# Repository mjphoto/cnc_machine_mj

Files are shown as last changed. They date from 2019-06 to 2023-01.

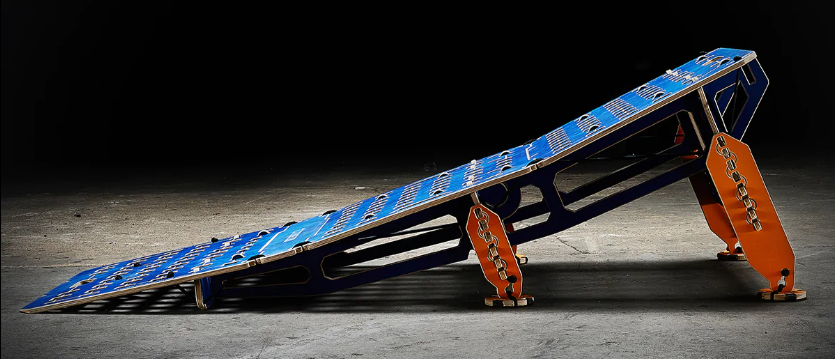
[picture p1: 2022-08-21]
CAD_Files/Bike Jump/MTB Hopper/Coach Low.PNG

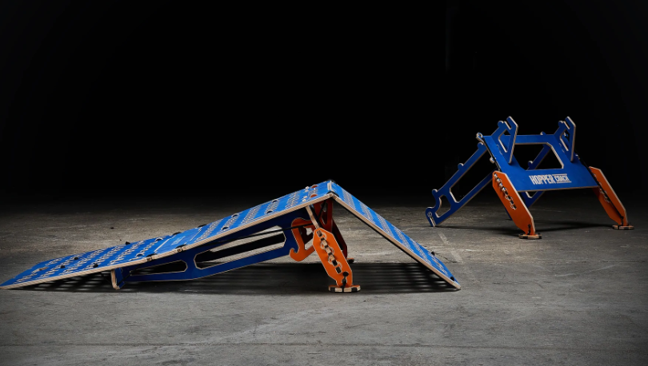
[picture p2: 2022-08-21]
CAD_Files/Bike Jump/MTB Hopper/Coacg.PNG

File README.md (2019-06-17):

# cnc_machine

## Software environment
### OS

Real time kernal support only comes with debian wheezy. I get better lancy times with the realtime kernel, but stretch with a preempt kernel complied is acceptable

In order to use wheezy souces.list needs to have entries changed to archive.debian.org and there are no security updates

### LinuxCNC

Stable linux cnc is 2.7. It seems that to sort out antiracking on the long axis (2 motors) we need to install linuxcnc 2.8

How to for config (as stepconf in 2.8 is a bit shit apparently):
https://forum.linuxcnc.org/49-basic-configuration/33079-how-to-2-or-more-motors-on-one-axis-gantry-linuxcnc-2-8-master

#### ToDo
* Check timings on TB6600 for ini file
* Check number of division of steps in driver that work well
* Suss out if linux cnc copes with sloping work bench
* Install stretch on big machine alongside wheezy
  * Upgrade to linuxCNC 2.8 and sort out racking correction on long axis
  * Refine ini and hal files

## Hardware stuff
### Links
* Working wiring diagram for motors
   * http://totcnc.com/img/cms/blog_img/090616/(JK02)BB5002_HY-DIV268N-5A(TB6600)part1.png

### Todo
* Work out attachemnt detail for parts we are working on
* A million other things

For using joypad (testing):
Page serves as a guide: http://wiki.linuxcnc.org/cgi-bin/wiki.pl?Simple_Remote_Pendant

First start xboxdrv:
```
sudo xboxdrv
```

Then start hal to map pins
```
mw@cnc:~$ halrun
halcmd: loadusr hal_input -d /devices/virtual/input/input15 -p Gamepad
halcmd: No input device matching '/devices/virtual/input/input15' was found (1 devices checked)

halcmd: loadusr hal_input -d /devices/virtual/input/input15 -p Gamepad
halcmd: No input device matching '/devices/virtual/input/input15' was found (1 devices checked)

halcmd: loadusr -W hal_input -KRAL Xbox
halcmd: loadusr halmeter
```

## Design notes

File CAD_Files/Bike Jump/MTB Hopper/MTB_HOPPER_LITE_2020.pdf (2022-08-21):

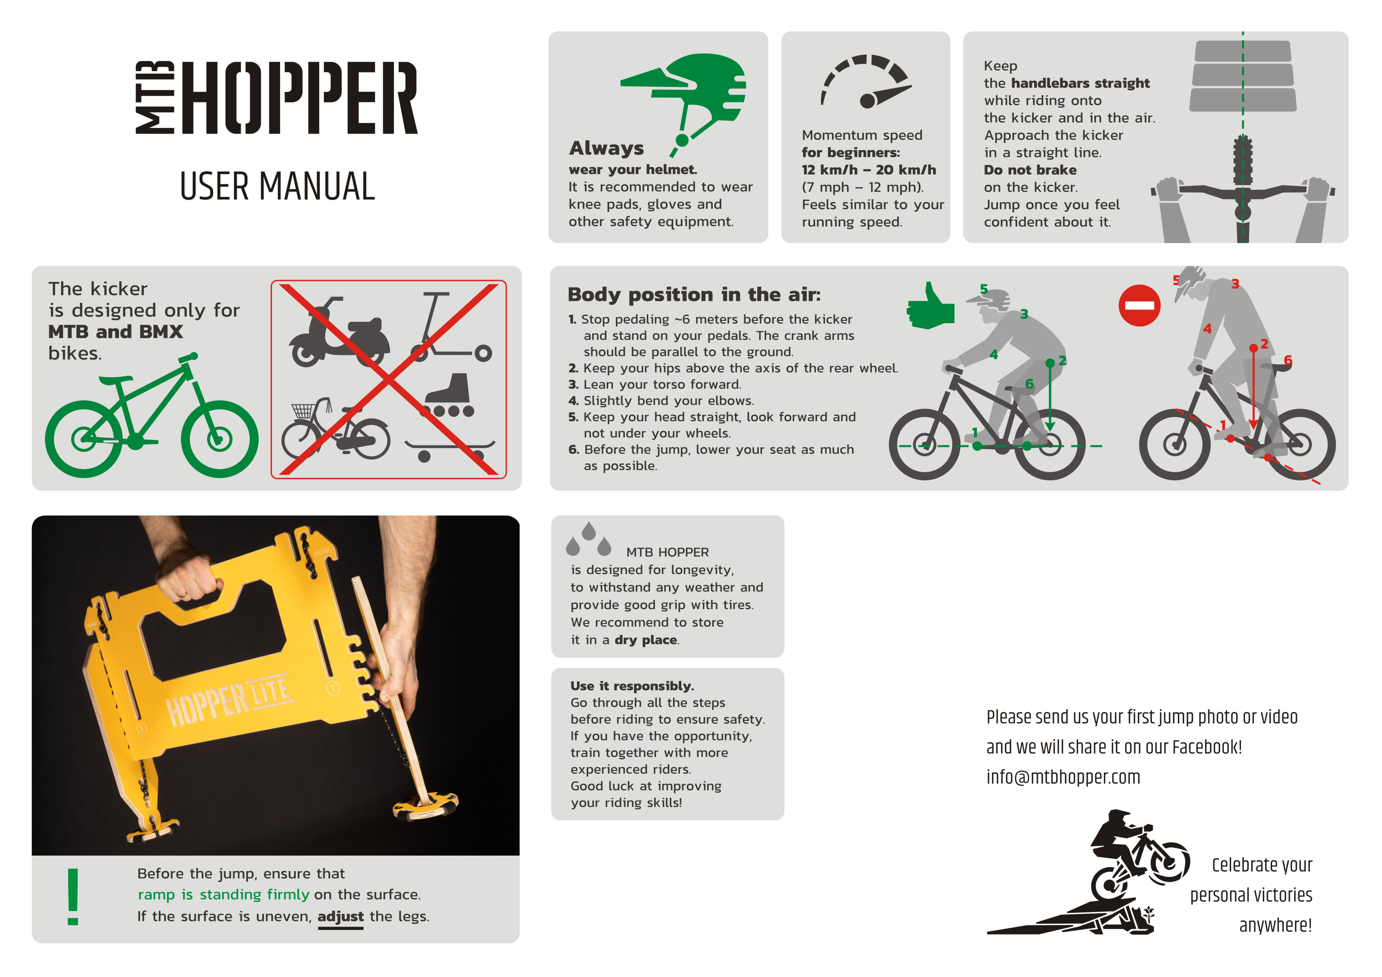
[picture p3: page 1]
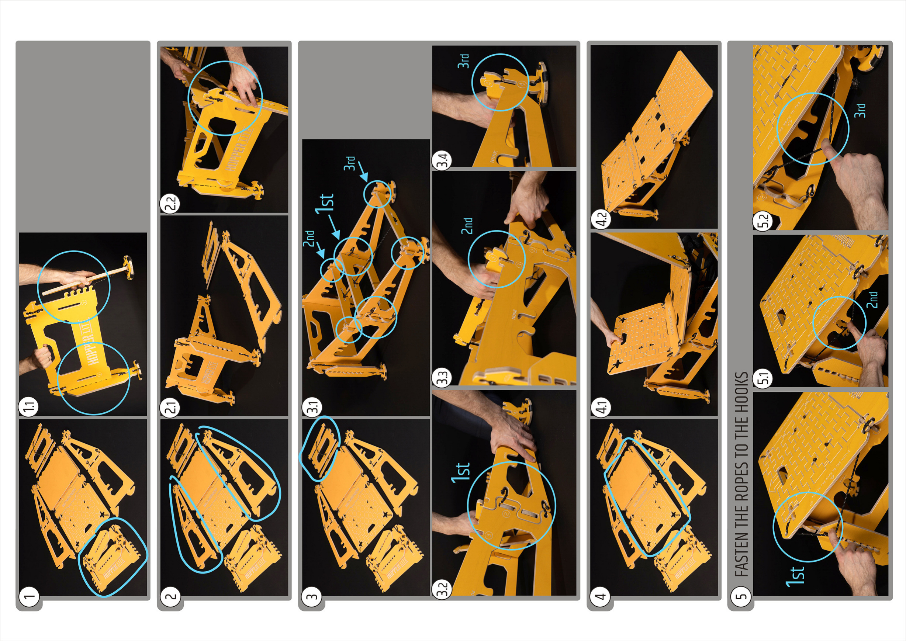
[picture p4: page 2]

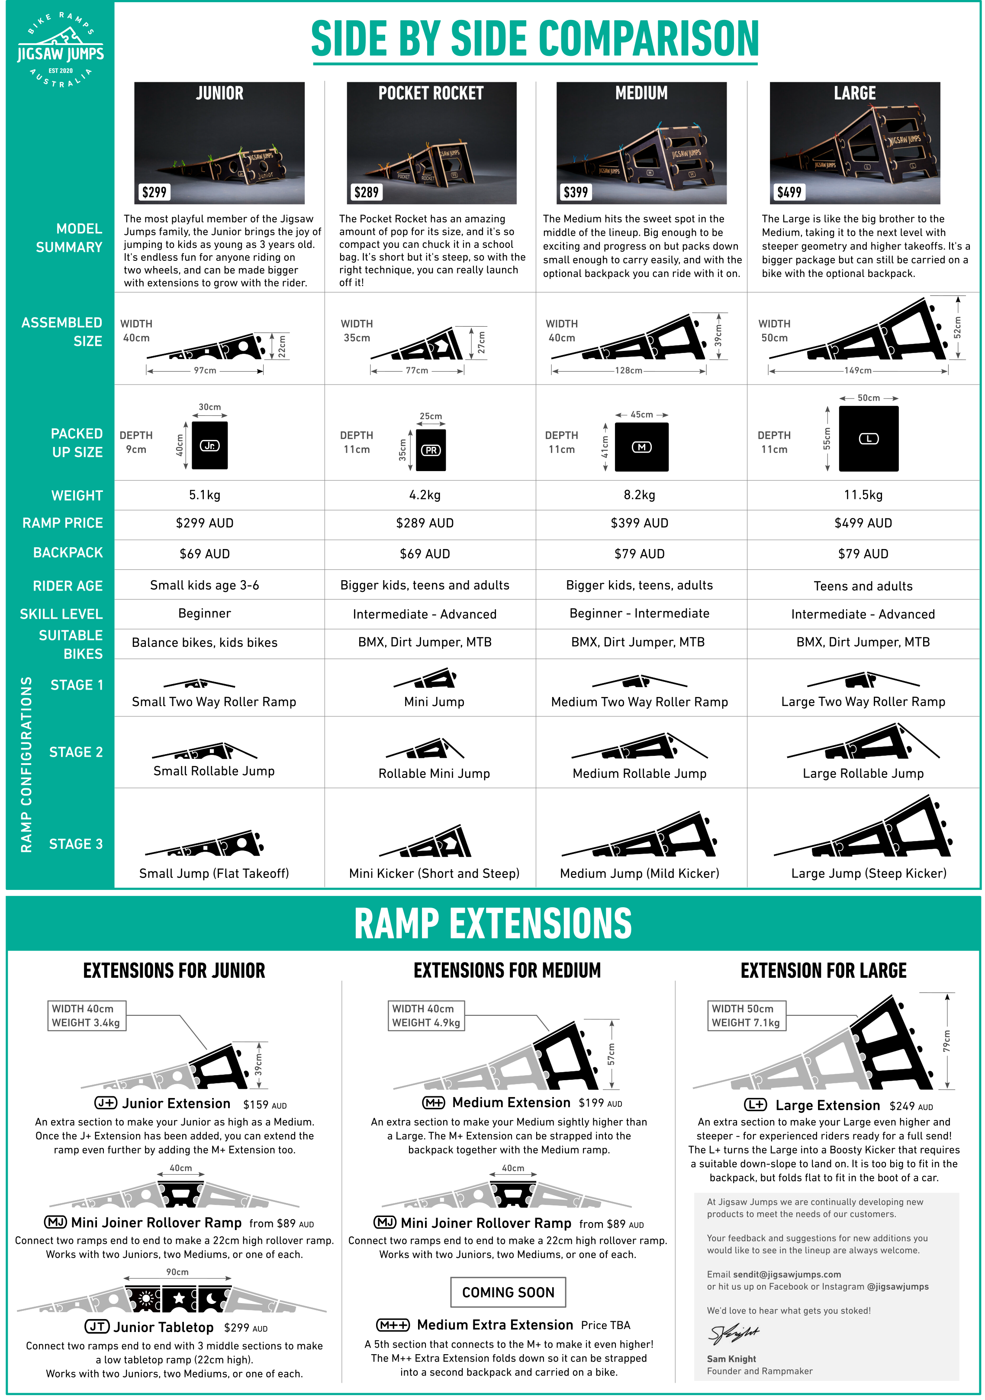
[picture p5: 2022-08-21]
CAD_Files/Bike Jump/JigSaw/Web_Comparison_Chart_v13.png

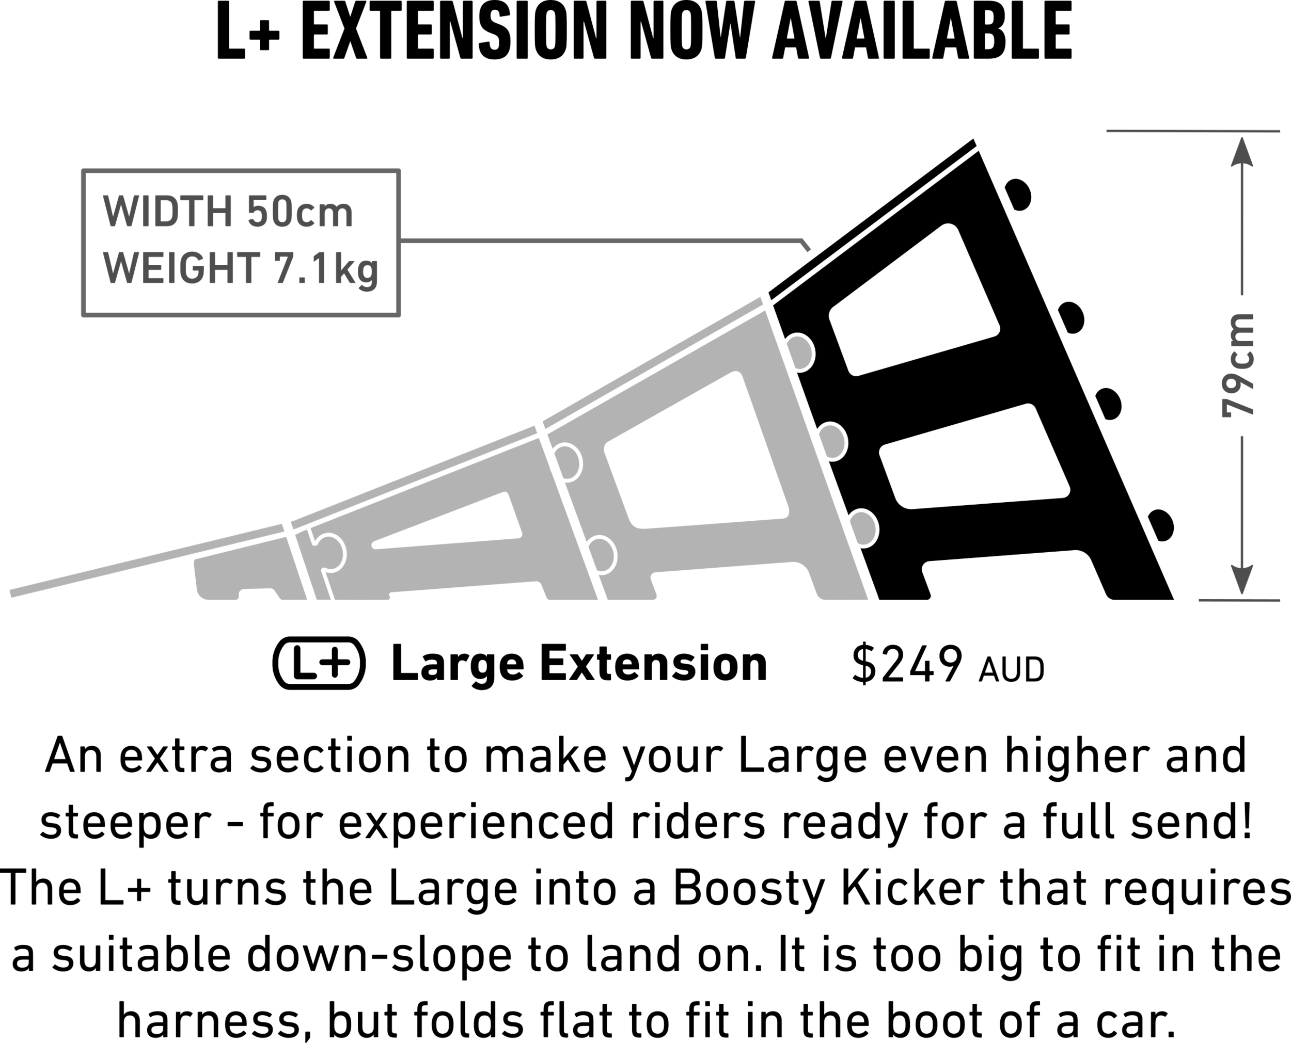
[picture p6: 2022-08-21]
CAD_Files/Bike Jump/JigSaw/L_Plus_Diagram.png

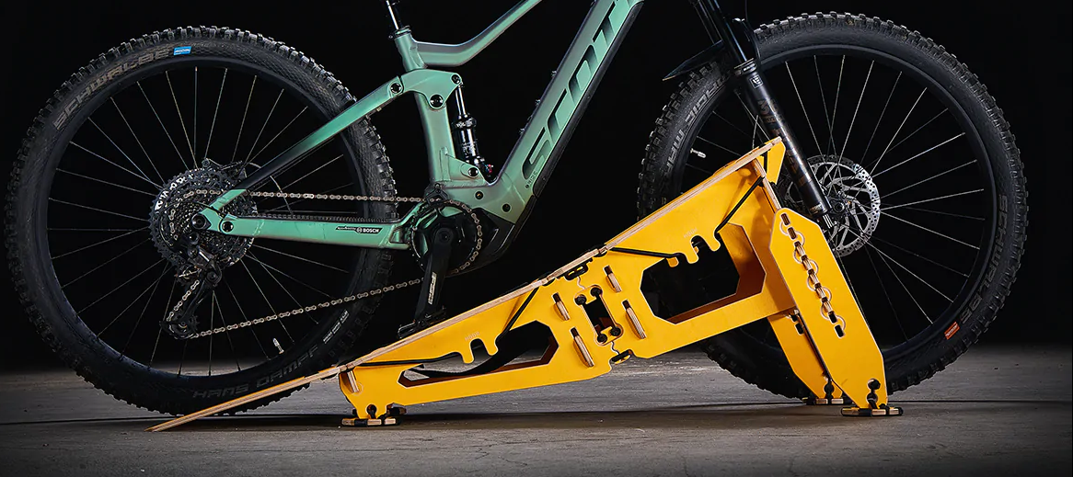
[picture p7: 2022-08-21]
CAD_Files/Bike Jump/MTB Hopper/LITE.PNG

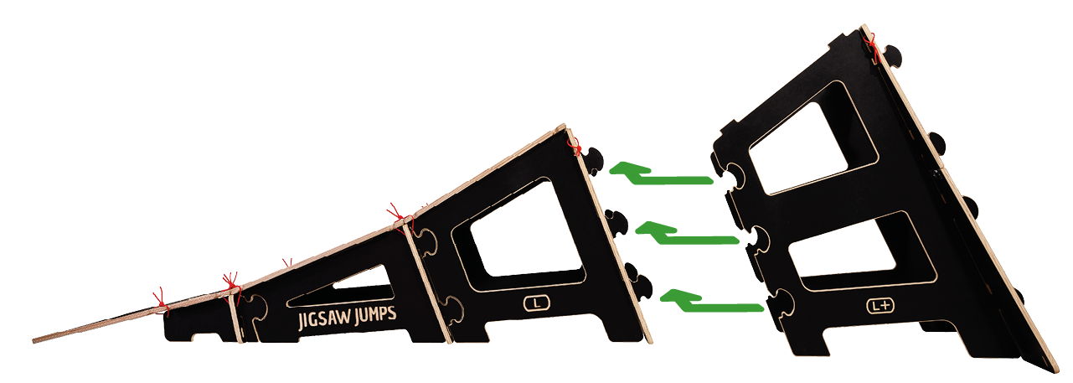
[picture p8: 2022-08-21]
CAD_Files/Bike Jump/JigSaw/L_Plus_Connect_to_Large.png

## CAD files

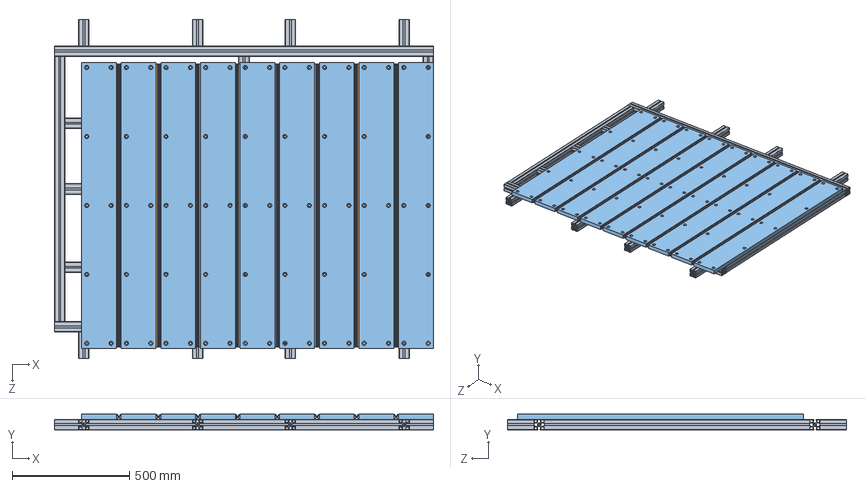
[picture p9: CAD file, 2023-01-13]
CAD_CNC_Machine/CNC_Machine_CAD_Short/CNC_SHORT_BedV2.SLDASM
1615.0 x 68.0 x 1445.0 mm
CNC_SHORT_Table minitec
CNC_SHORT_2020 x 8
CNC_SHORT_BedBoardV2 x 9

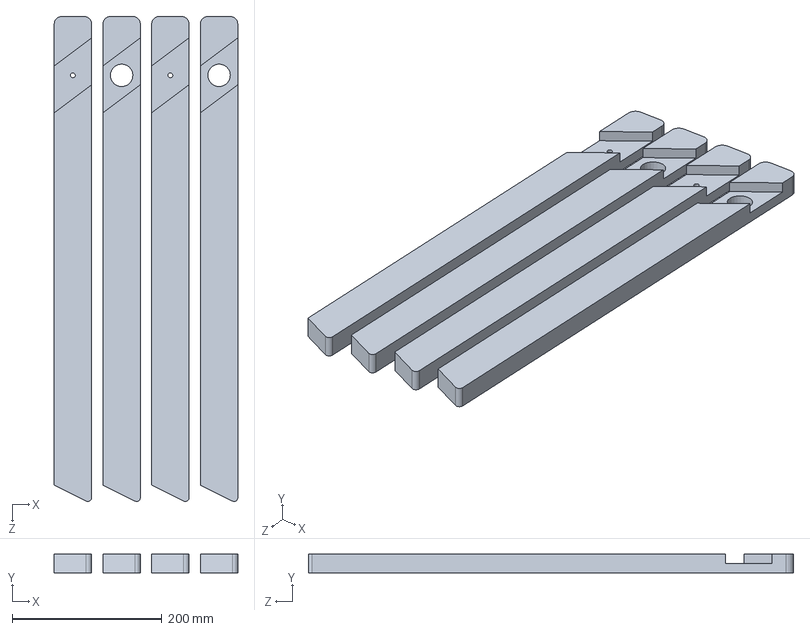
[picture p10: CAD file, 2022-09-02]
CAD_Files/Baby Play Gym/Assem1.SLDASM
245.0 x 25.0 x 646.9 mm
PlayGym x 4

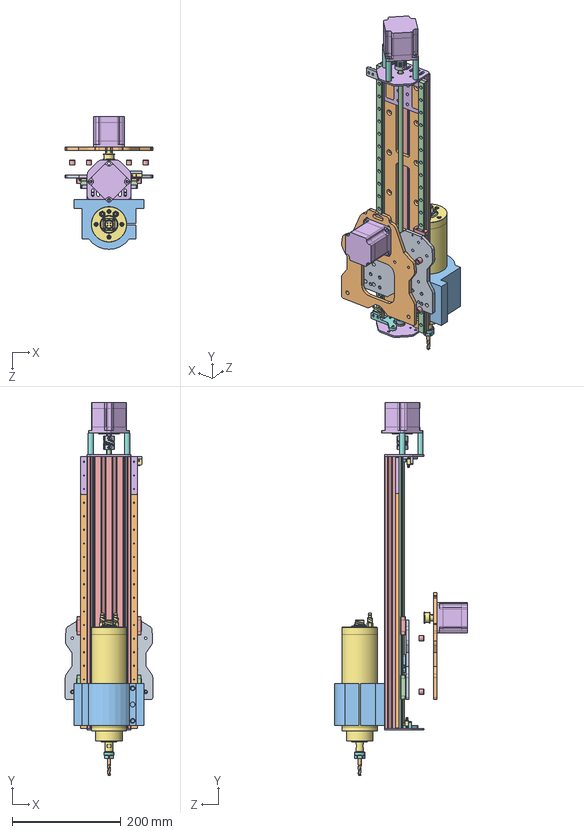
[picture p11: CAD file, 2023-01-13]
CAD_CNC_Machine/CNC_Machine_CAD_Short/CNC_SHORT_y-z gantry-large-revied.SLDASM
160.9 x 685.4 x 244.0 mm
CNC_SHORT_X Axis Tall Front Plate_6mm - Build 80_11.15.14
CNC_SHORT_X Axis Rear Plate_6mm - Build 80_11.15.14
CNC_SHORT_8mm Acme Anti Backlash Nut Block
CNC_SHORT_Nylon Insert Lock Nut M5 x 4
CNC_SHORT_Aluminum Spacer 9mm x 6
CNC_SHORT_Nema 23 Stepper Motor x 2
CNC_SHORT_GT3 Timing Pulley 20 Tooth
CNC_SHORT_Aluminum Spacer 40mm x 3
CNC_SHORT_Flexible Coupling 0.25in x 8mm
CNC_SHORT_Ball Bearing 8 x 16 x 5 x 2
CNC_SHORT_Lock Collar 8mm x 2
CNC_SHORT_8mm leadscrew 520mm
CNC_SHORT_V-Slot 20x80x500 Linear Rail
CNC_SHORT_Threaded Rod Plate Nema 23 x 2
CNC_SHORT_GDK58-24Z_0.8
CNC_SHORT_Nut ER11 Type A
CNC_SHORT_COLLET ER11 d6-
CNC_SHORT_Фреза
CNC_SHORT_Spindle Holder
CNC_SHORT_MGN12H1R100ZFC x 4
CNC_SHORT_MGN12C1R100ZFC x 2
CNC_SHORT_Micro Limit Switch x 2
Part2^CNC_SHORT_y-z gantry-large-revied
Part3^CNC_SHORT_y-z gantry-large-revied
CNC_SHORT_CNC-01-1015

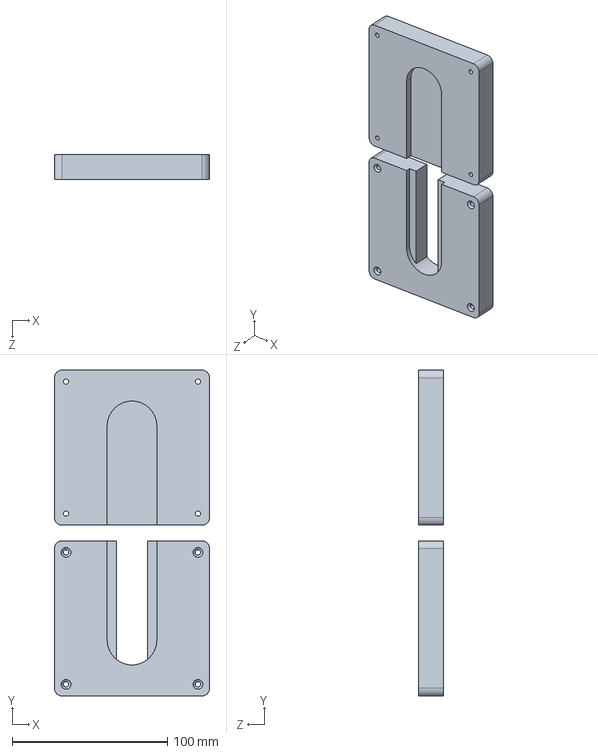
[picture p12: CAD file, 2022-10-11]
CAD_Files/Monitor Mount/Assem1.SLDASM
100.0 x 210.0 x 16.0 mm
Monitor_mount x 2

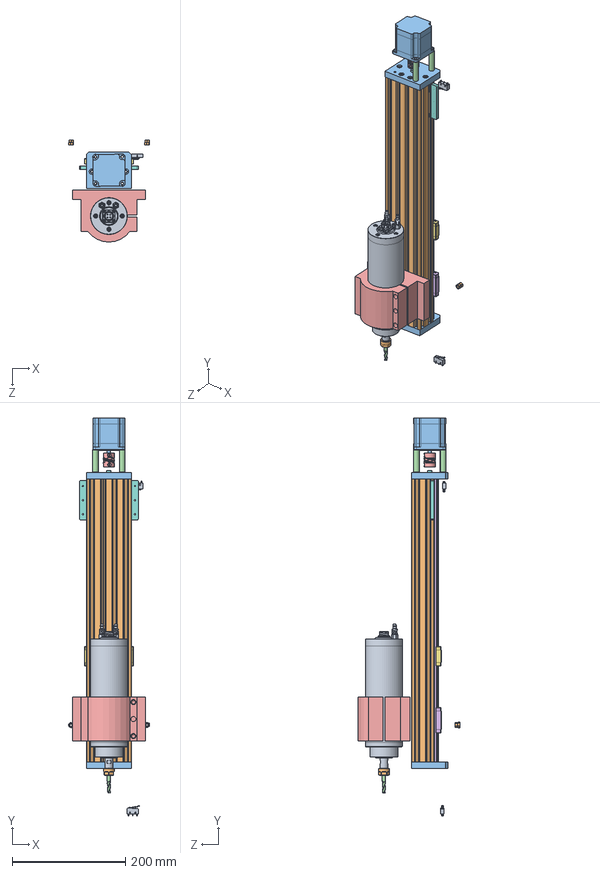
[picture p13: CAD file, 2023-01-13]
CAD_CNC_Machine/CNC_Machine_CAD_Short/CNC_SHORT_y-z gantry-large-revised2.SLDASM
143.7 x 703.7 x 180.6 mm
CNC_SHORT_8mm Acme Anti Backlash Nut Block
CNC_SHORT_Nylon Insert Lock Nut M5 x 4
CNC_SHORT_Nema 23 Stepper Motor
CNC_SHORT_Aluminum Spacer 40mm x 3
CNC_SHORT_Flexible Coupling 0.25in x 8mm
CNC_SHORT_Ball Bearing 8 x 16 x 5 x 2
CNC_SHORT_Lock Collar 8mm x 2
CNC_SHORT_8mm leadscrew 520mm
CNC_SHORT_GDK58-24Z_0.8
CNC_SHORT_Nut ER11 Type A
CNC_SHORT_COLLET ER11 d6-
CNC_SHORT_Фреза
CNC_SHORT_Spindle Holder
CNC_SHORT_MGN12H1R100ZFC x 4
CNC_SHORT_MGN12C1R100ZFC x 2
CNC_SHORT_Micro Limit Switch x 2
V-Slot C-Beam
C-Beam End Plate x 2

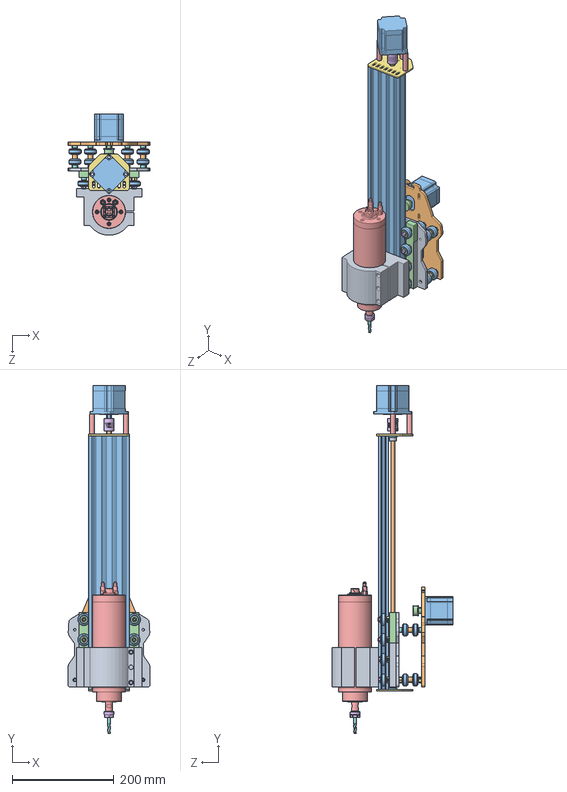
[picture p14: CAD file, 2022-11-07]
CAD_CNC_Machine/CNC_Machine_CAD_Short/CNC_SHORT_y-z gantry-large.SLDASM
160.9 x 685.4 x 239.1 mm
X Axis Tall Front Plate_6mm - Build 80_11.15.14
X Axis Rear Plate_6mm - Build 80_11.15.14
Xtreme Solid V Wheel x 20
Ball Bearing 5 x 16 x 5 x 40
Precision Shim 10 x 5 x 1 x 40
Nylon Insert Lock Nut M5 x 20
Eccentric Spacer 6mm x 8
Aluminum Spacer 6mm x 12
8mm Acme Anti Backlash Nut Block
Aluminum Spacer 9mm x 6
Nema 23 Stepper Motor x 2
GT3 Timing Pulley 20 Tooth
Aluminum Spacer 40mm x 3
Flexible Coupling 0.25in x 8mm
Threaded Rod Plate Nema 23 x 2
Ball Bearing 8 x 16 x 5 x 2
Lock Collar 8mm x 2
8mm leadscrew 520mm
V-Slot 20x80x500 Linear Rail
spacer block large x 2
GDK58-24Z_0.8
Nut ER11 Type A
COLLET ER11 d6-
Фреза
Spindle Holder

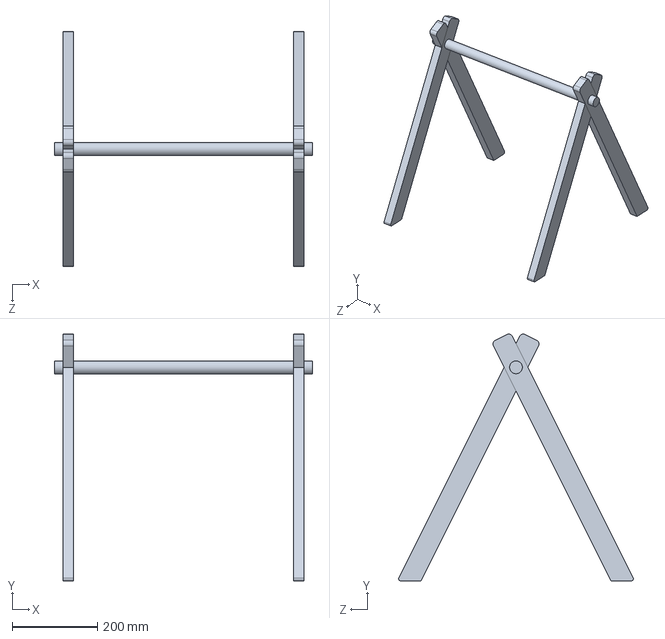
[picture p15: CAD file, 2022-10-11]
CAD_Files/Baby Play Gym/PlayGym.SLDPRT
604.0 x 578.0 x 549.7 mm

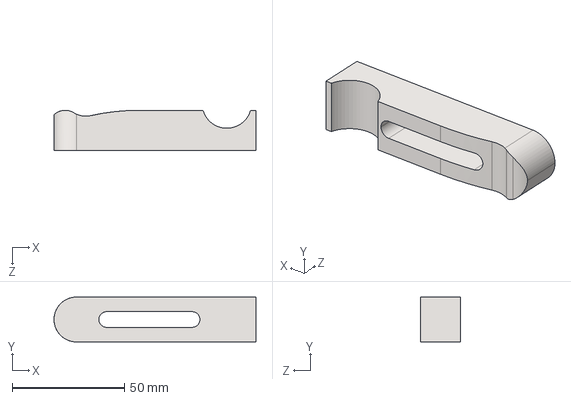
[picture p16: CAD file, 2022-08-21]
CAD_Files/CNC Clamps/Clamp_90mm.STEP
90.0 x 20.0 x 18.0 mm

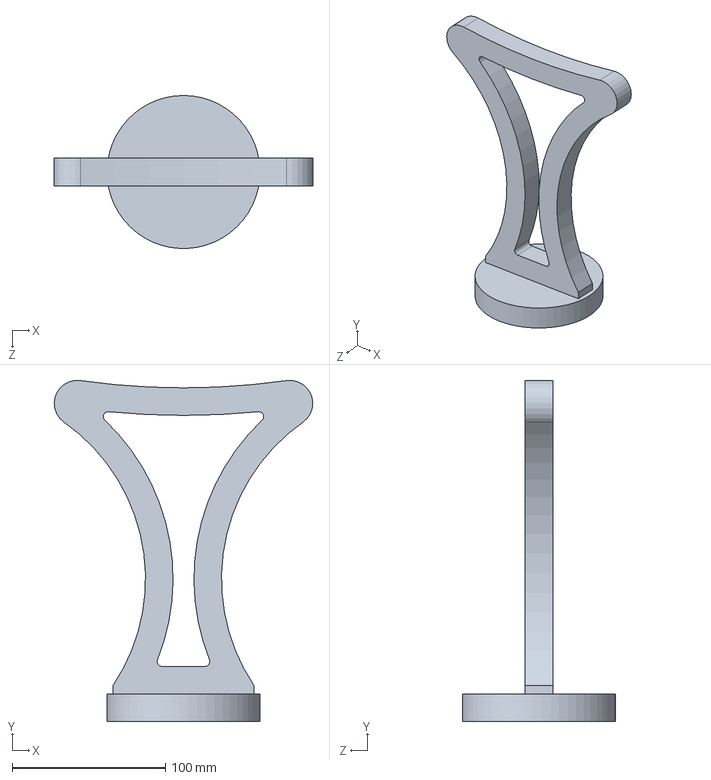
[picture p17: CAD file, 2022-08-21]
CAD_Files/HeadphoneStand.SLDPRT
169.0 x 222.8 x 100.0 mm

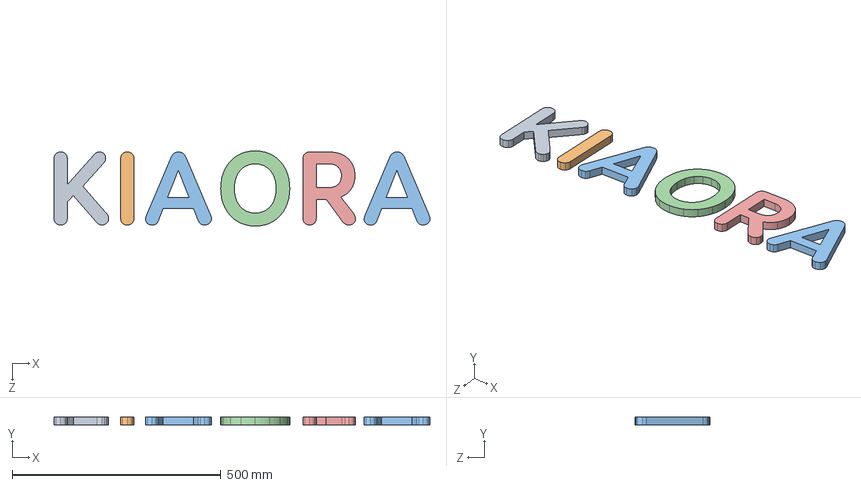
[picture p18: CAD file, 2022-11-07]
CAD_Files/kIAoRA/kIAOra.STEP
901.0 x 18.0 x 180.1 mm

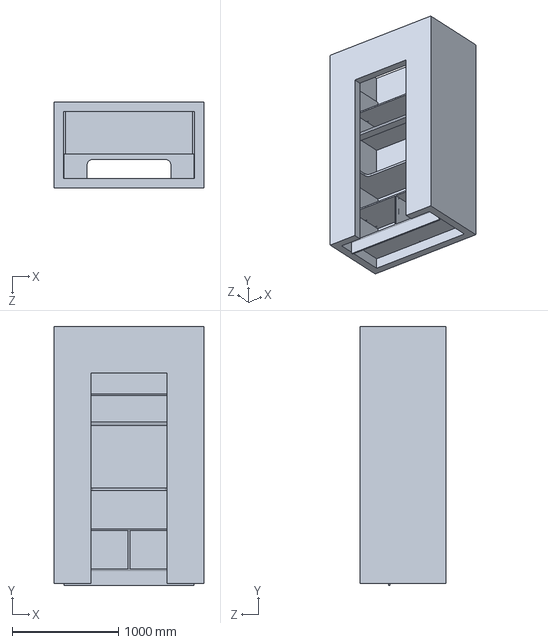
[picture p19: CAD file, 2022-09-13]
CAD_Files/Kitchen Cupboard/Wardrobe.SLDPRT
1407.5 x 2435.0 x 807.0 mm

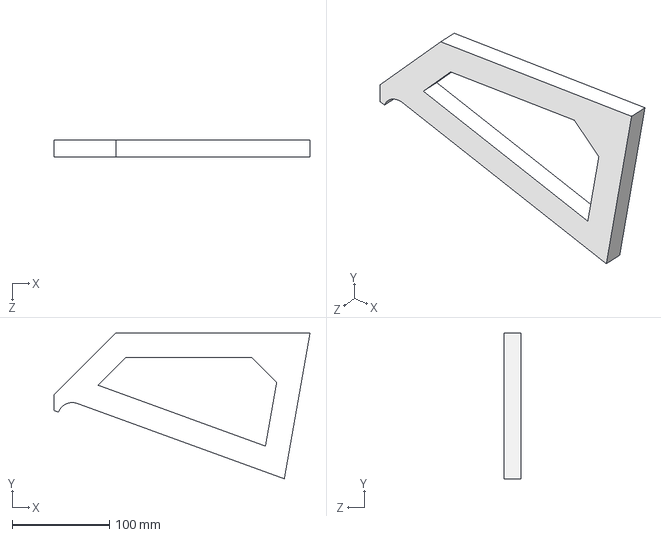
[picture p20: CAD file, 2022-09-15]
CAD_Files/Laptop Stand/Laptop Stand 1.STEP
263.7 x 150.0 x 18.0 mm

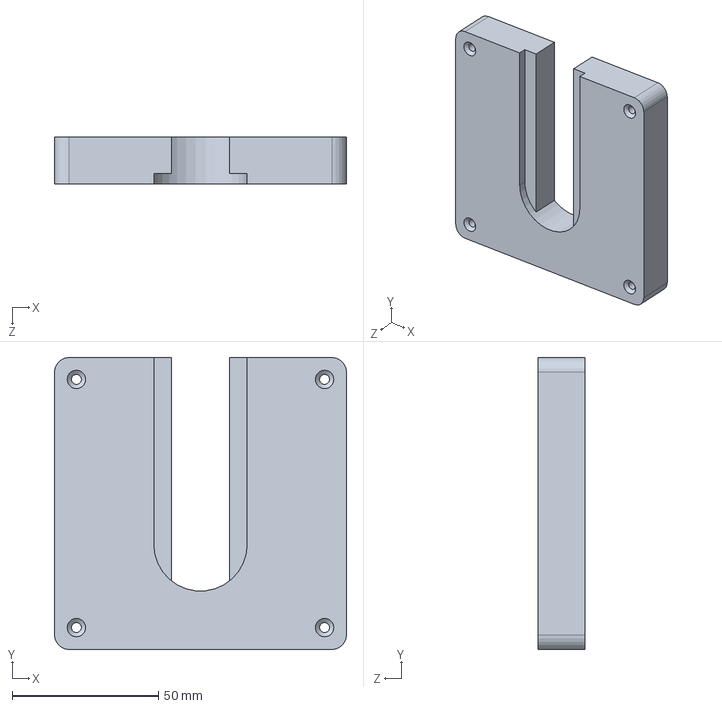
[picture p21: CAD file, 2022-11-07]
CAD_Files/Monitor Mount/Monitor_mount.SLDPRT
100.0 x 100.0 x 16.0 mm

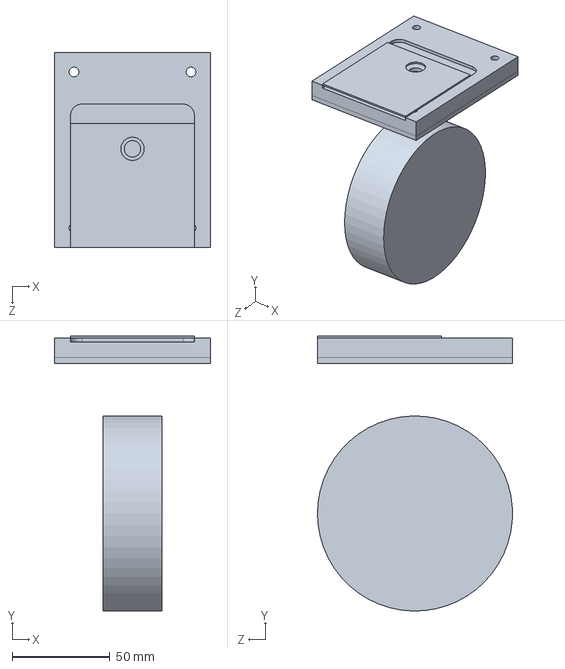
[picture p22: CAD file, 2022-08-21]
CAD_Files/Workbench/BenchWheelSpacer.SLDPRT
80.0 x 141.0 x 100.0 mm

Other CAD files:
CAD_Files/Baby Play Gym/PlayGym_Assy_Cut.STEP
CAD_CNC_Machine/CNC_Machine_CAD_Short/CNC_SHORT_Xtreme V Wheel.SLDASM
CAD_CNC_Machine/CNC_Machine_CAD_Short/CNC_SHORT_Y Gantry - LArge Plates and Beams.SLDASM
CAD_Files/Bike Jump/Geo Comparison.SLDPRT
CAD_CNC_Machine/CNC_Machine_CAD_Short/C-Beam End Plate.SLDPRT
CAD_CNC_Machine/CNC_Machine_CAD_Short/CNC_SHORT_2020.SLDPRT
CAD_CNC_Machine/CNC_Machine_CAD_Short/CNC_SHORT_8mm Acme Anti Backlash Nut Block.SLDPRT
CAD_CNC_Machine/CNC_Machine_CAD_Short/CNC_SHORT_8mm leadscrew 520mm.SLDPRT
CAD_CNC_Machine/CNC_Machine_CAD_Short/CNC_SHORT_Aluminium bed threaded bar.SLDPRT
CAD_CNC_Machine/CNC_Machine_CAD_Short/CNC_SHORT_Aluminum Spacer 40mm.SLDPRT
CAD_CNC_Machine/CNC_Machine_CAD_Short/CNC_SHORT_Aluminum Spacer 6mm.SLDPRT
CAD_CNC_Machine/CNC_Machine_CAD_Short/CNC_SHORT_Aluminum Spacer 9mm.SLDPRT
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

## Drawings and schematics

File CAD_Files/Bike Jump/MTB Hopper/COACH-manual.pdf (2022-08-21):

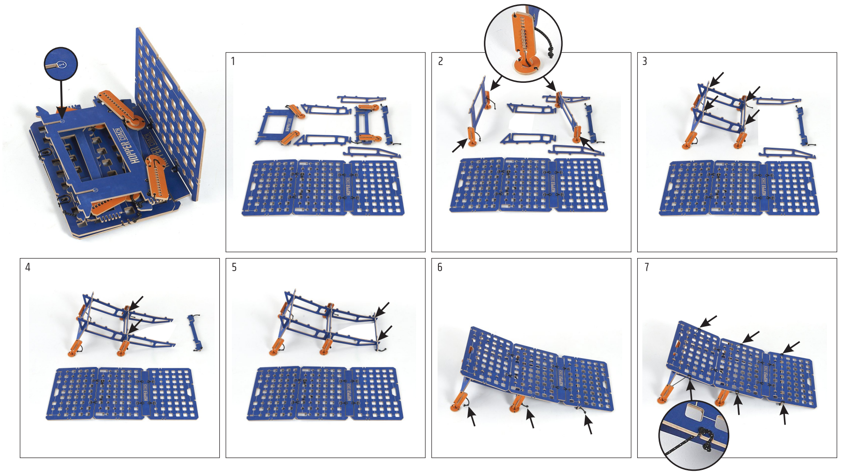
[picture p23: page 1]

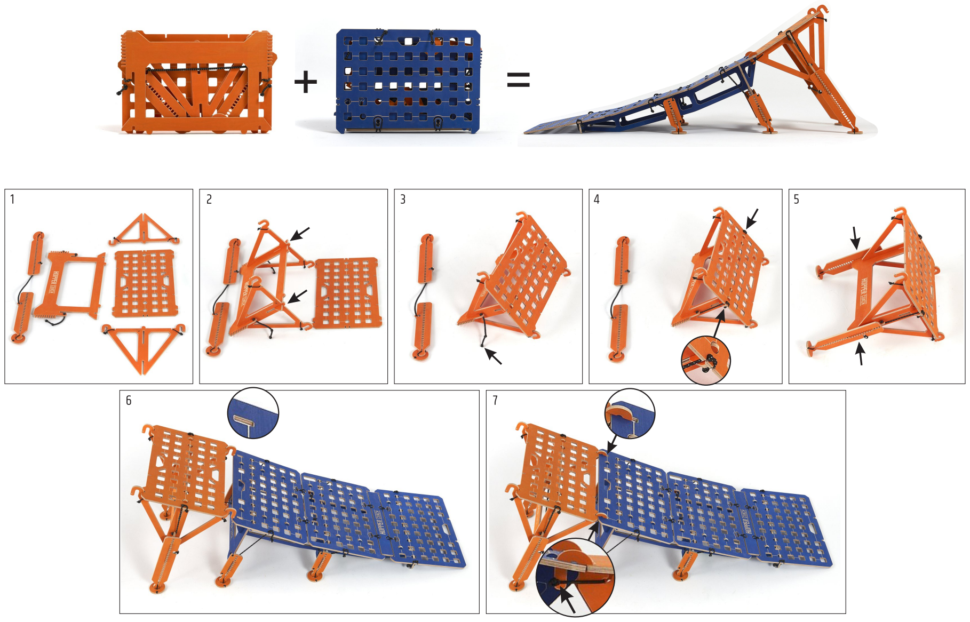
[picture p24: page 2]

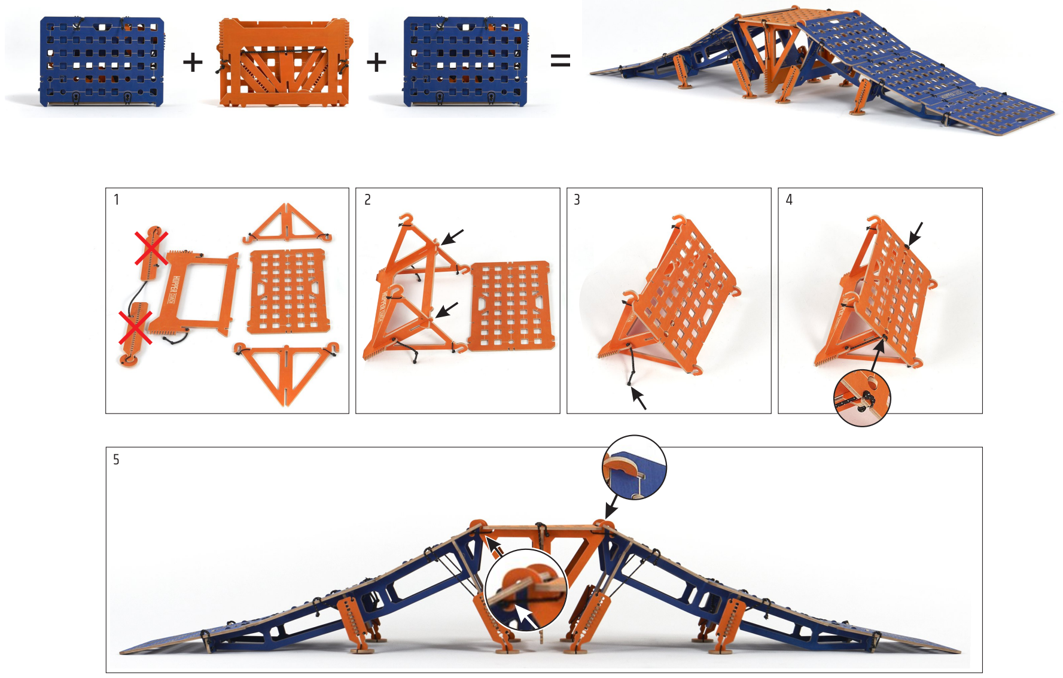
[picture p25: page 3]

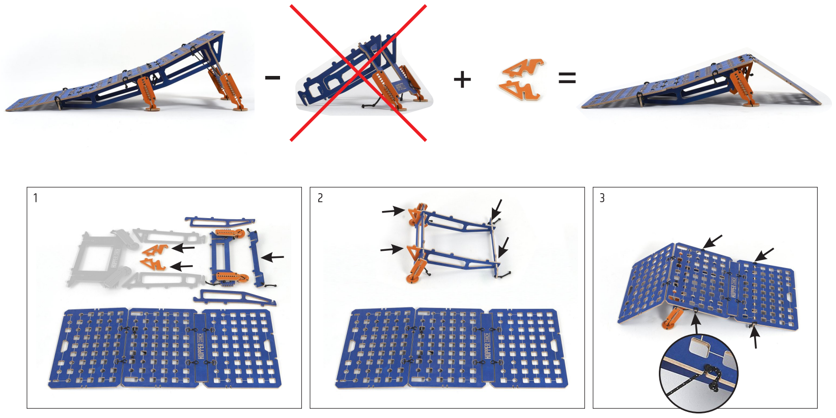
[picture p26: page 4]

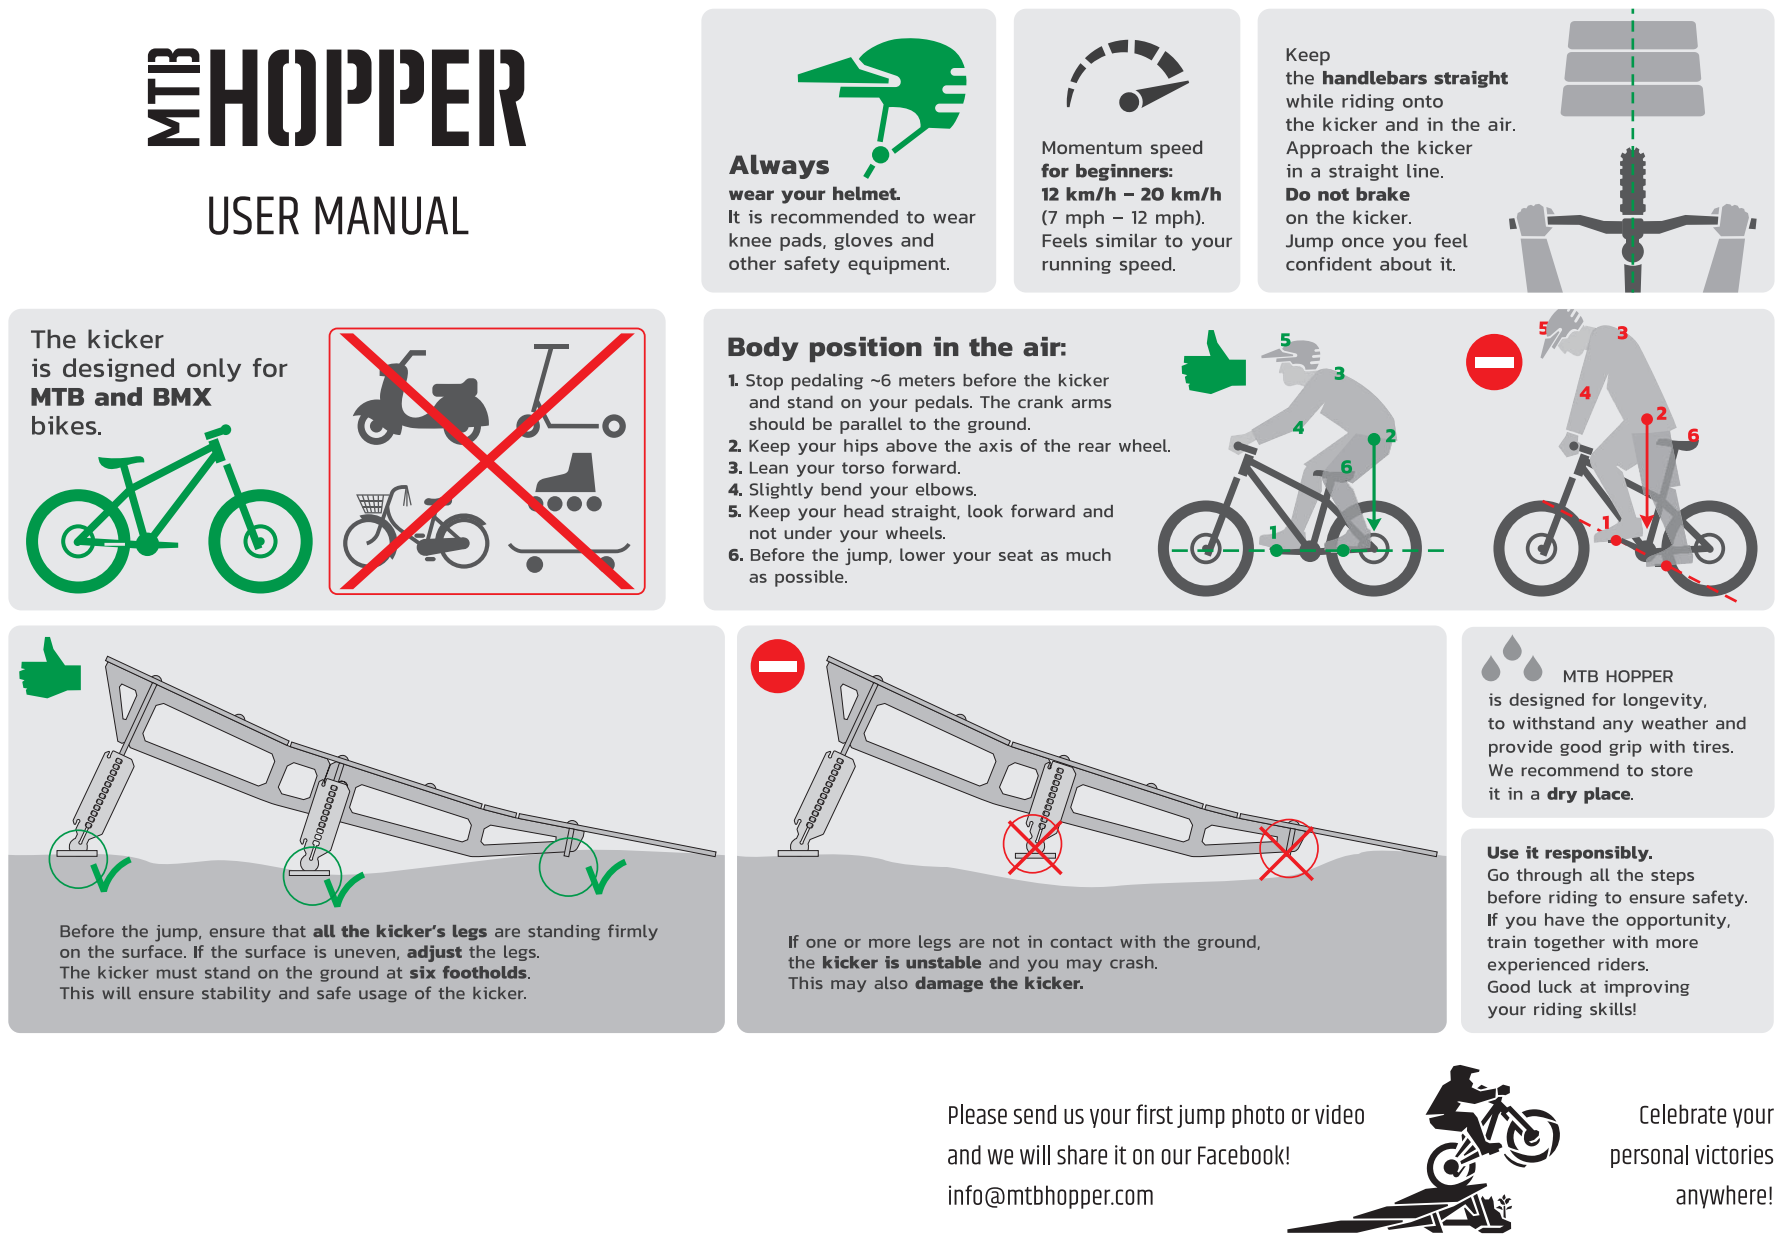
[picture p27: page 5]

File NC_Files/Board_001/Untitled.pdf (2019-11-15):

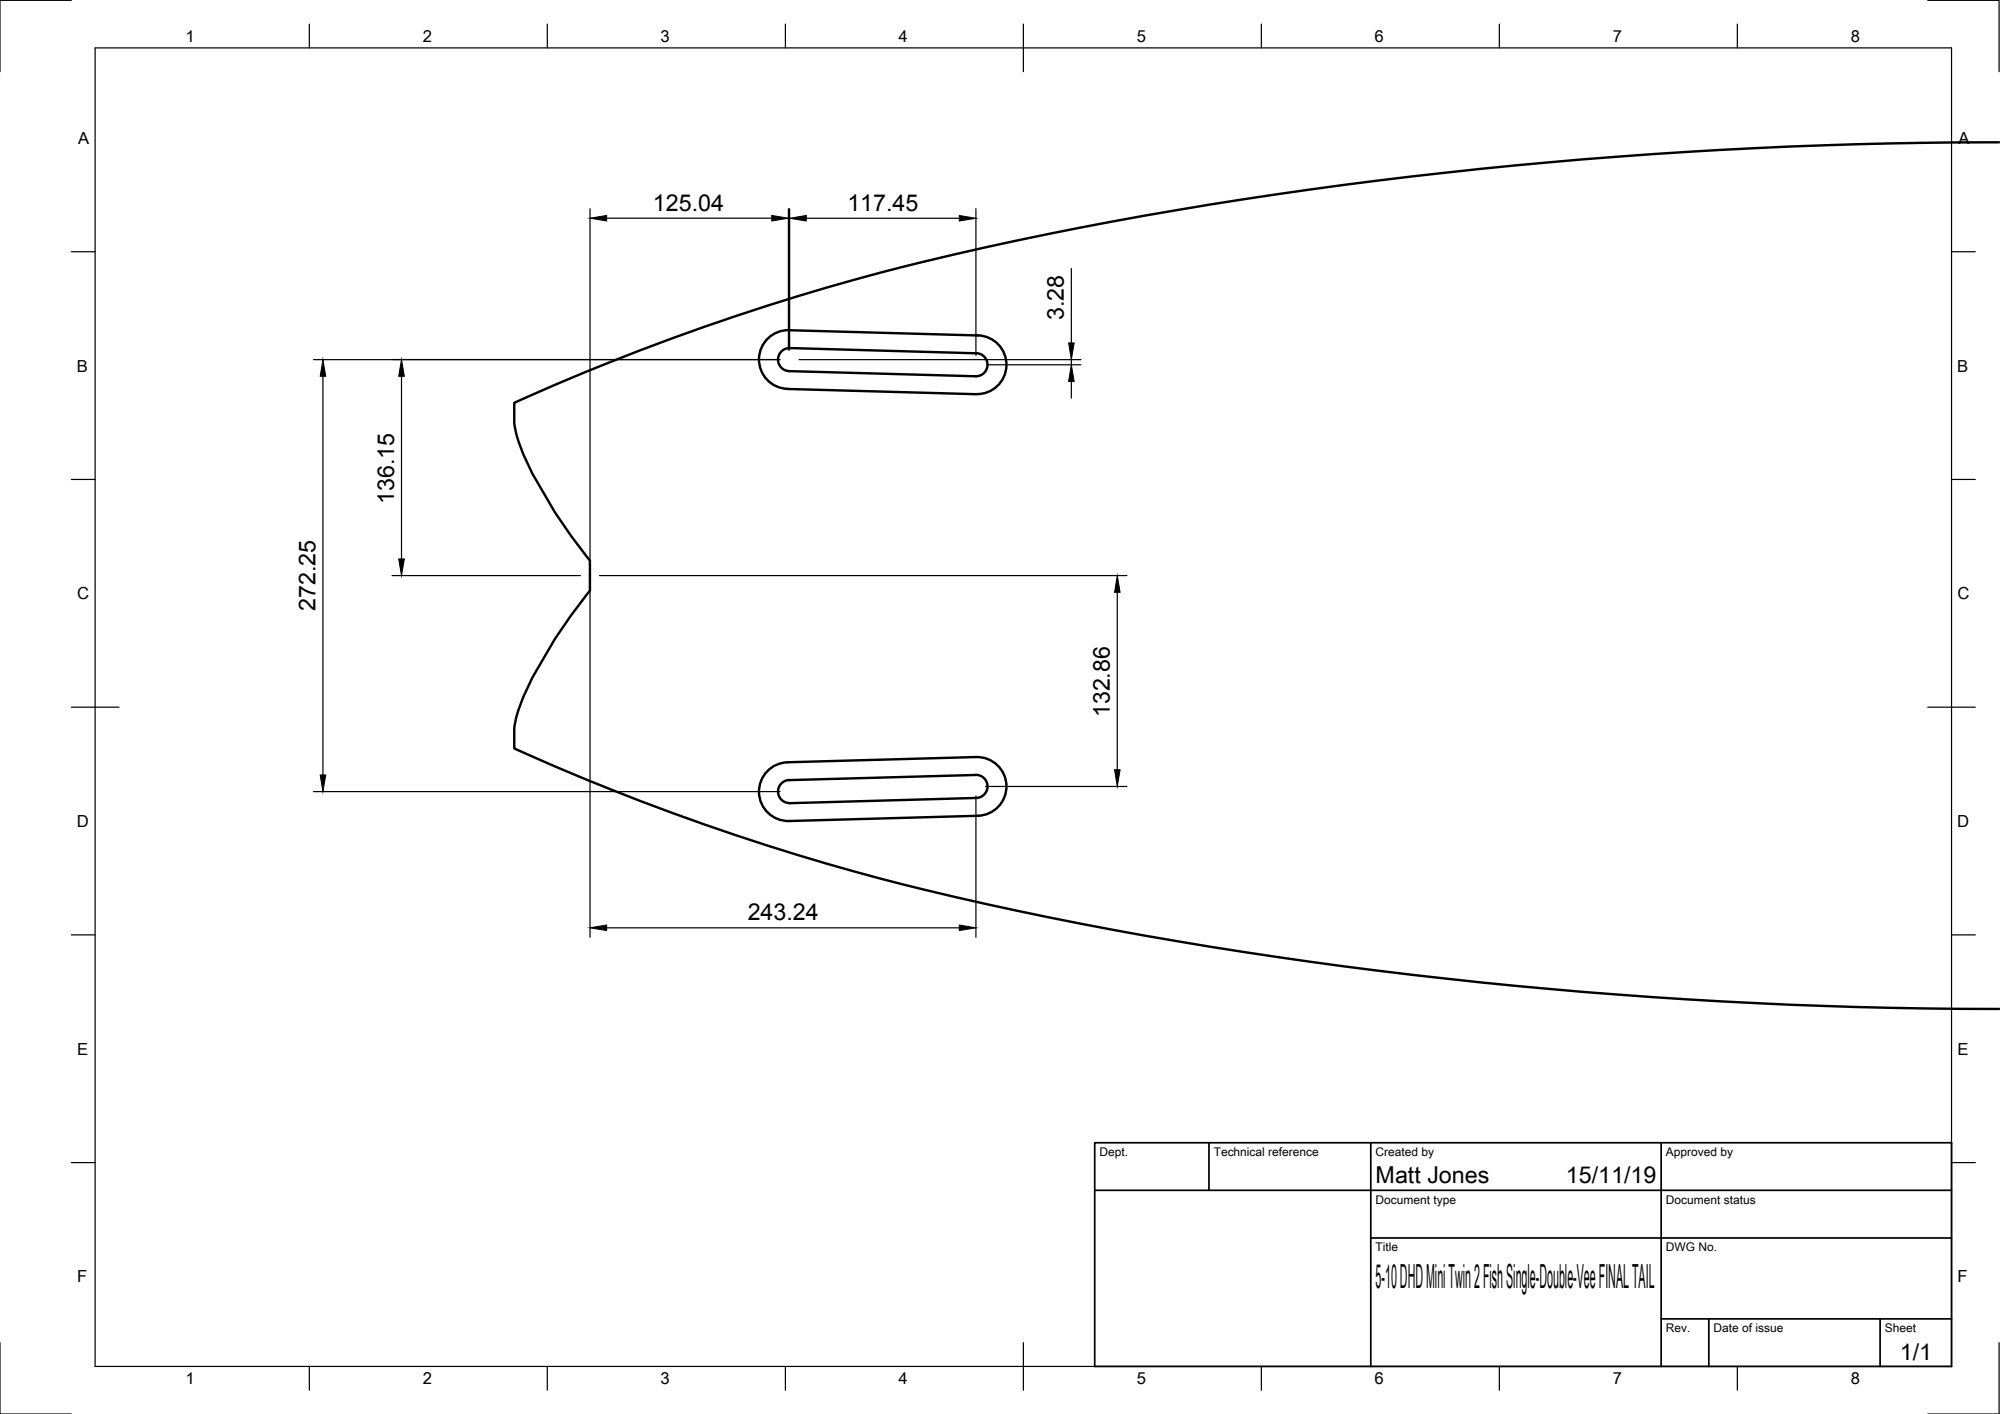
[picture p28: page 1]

Dept. | Technical reference | Created by Matt Jones 15/11/19 | Approved by

Document type | Document status

Title 5-10 DHD Mini Twin 2 Fish Single-Double-Vee FINAL TAIL | DWG No.

Rev. | Date of issue | Sheet 1/1

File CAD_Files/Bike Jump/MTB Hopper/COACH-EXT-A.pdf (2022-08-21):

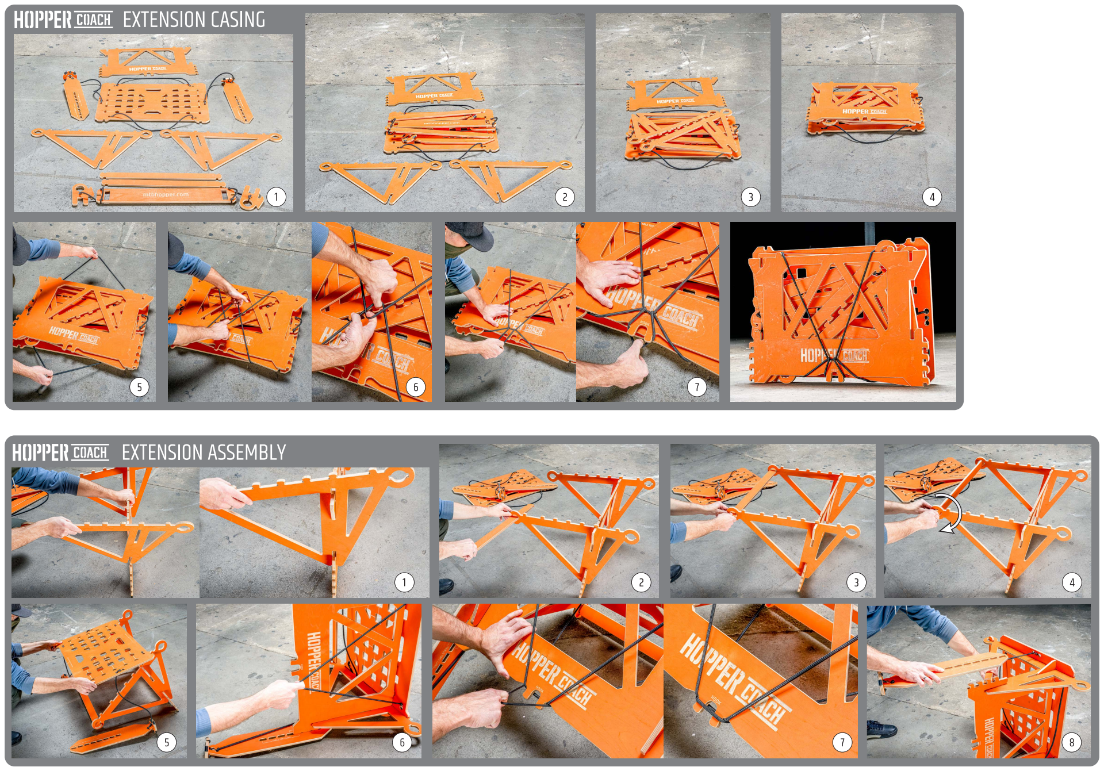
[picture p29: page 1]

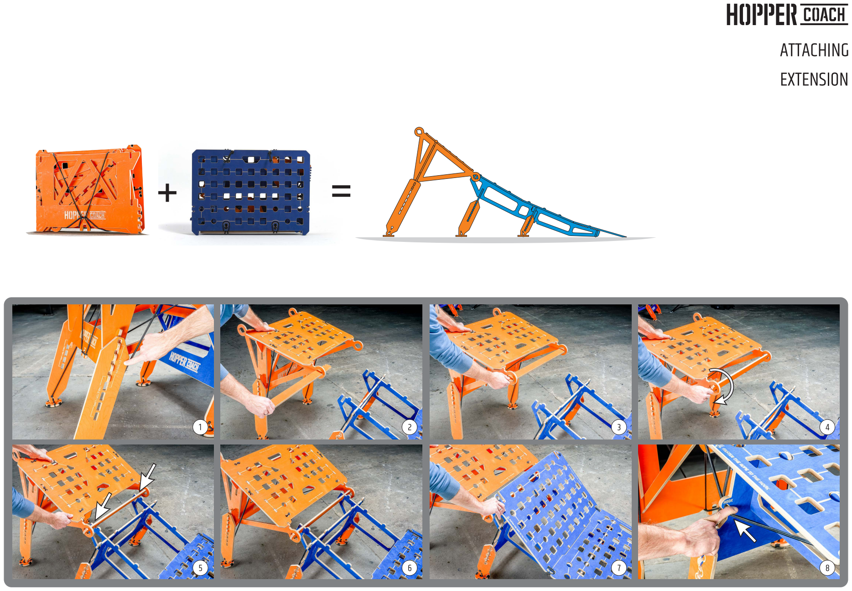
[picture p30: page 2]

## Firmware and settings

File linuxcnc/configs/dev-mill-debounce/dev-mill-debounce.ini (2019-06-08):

[EMC]
MACHINE = dev-mill-debounce
DEBUG = 0
VERSION = 1.1

[DISPLAY]
# following for custom buttons for touch off plate
# see http://7xcnc.com/software/probing/z-touch-plate/
PYVCP = custompanel.xml
DISPLAY = axis
EDITOR = gedit
POSITION_OFFSET = RELATIVE
POSITION_FEEDBACK = ACTUAL
ARCDIVISION = 64
GRIDS = 10mm 20mm 50mm 100mm 1in 2in 5in 10in
MAX_FEED_OVERRIDE = 1.2
MIN_SPINDLE_OVERRIDE = 0.5
MAX_SPINDLE_OVERRIDE = 1.2
DEFAULT_LINEAR_VELOCITY = 2.50
MIN_LINEAR_VELOCITY = 0
MAX_LINEAR_VELOCITY = 100.00
INTRO_GRAPHIC = linuxcnc.gif
INTRO_TIME = 5
PROGRAM_PREFIX = /home/mw/linuxcnc/nc_files
INCREMENTS = 5mm 1mm .5mm .1mm .05mm .01mm .005mm

[KINS]
JOINTS = 4
KINEMATICS = trivkins coordinates=XYYZ

[FILTER]
PROGRAM_EXTENSION = .png,.gif,.jpg Greyscale Depth Image
PROGRAM_EXTENSION = .py Python Script
PROGRAM_EXTENSION = .nc,.tap G-Code File
png = image-to-gcode
gif = image-to-gcode
jpg = image-to-gcode
py = python

[TASK]
TASK = milltask
CYCLE_TIME = 0.010

[RS274NGC]
PARAMETER_FILE = linuxcnc.var

[EMCMOT]
EMCMOT = motmod
COMM_TIMEOUT = 1.0
BASE_PERIOD = 100000
SERVO_PERIOD = 1000000

[HAL]
HALUI = halui
HALFILE = dev-mill-debounce.hal
HALFILE = custom.hal
POSTGUI_HALFILE = postgui_call_list.hal

# following block added:
[HALUI]
# add halui MDI commands here (max 64)
MDI_COMMAND = o100 call
MDI_COMMAND = o101 call
MDI_COMMAND = o102 call

[TRAJ]
COORDINATES =  X Y Y Z
LINEAR_UNITS = mm
ANGULAR_UNITS = degree
DEFAULT_LINEAR_VELOCITY = 10.0
MAX_LINEAR_VELOCITY = 100.00

[EMCIO]
EMCIO = io
CYCLE_TIME = 0.100
TOOL_TABLE = tool.tbl

[AXIS_X]
MAX_VELOCITY = 100.0
MAX_ACCELERATION = 750.0
MIN_LIMIT = -0.001
MAX_LIMIT = 1300.0

[JOINT_0]
TYPE = LINEAR
MIN_LIMIT = -0.001
MAX_LIMIT = 1350.0
MAX_VELOCITY = 100.0
MAX_ACCELERATION = 750.0
STEPGEN_MAXACCEL = 937.5
SCALE = 40.0
FERROR = 1
MIN_FERROR = .25
HOME = 20.0
HOME_OFFSET = 0.0
# To close switch, slowly open then drive to home position:
# If you press the minus key to move the axis toward the home switch then all homing values will be negative number?
# see http://wiki.linuxcnc.org/cgi-bin/wiki.pl?Homing_And_Limit_Switch
HOME_SEARCH_VEL = -100.00
HOME_LATCH_VEL = 3.00000
# To close switch, back off and move in slowly, then head to home:
#HOME_SEARCH_VEL = 20.00
#HOME_LATCH_VEL = 1.500000
# may need to set this to a negative number if homing in wrong direction (in 2.7 it must be a postive number...)
HOME_FINAL_VEL = 25
HOME_IGNORE_LIMITS = YES
HOME_SEQUENCE = 1
VOLATILE_HOME = 1
USE_HOME_INDEX = NO

[AXIS_Y]
MAX_VELOCITY = 100.0
MAX_ACCELERATION = 750.0
MIN_LIMIT = -0.001
MAX_LIMIT = 2740.0

[JOINT_1]
TYPE = LINEAR
MIN_LIMIT = -0.001
MAX_LIMIT = 2740.0
MAX_VELOCITY = 100.0
MAX_ACCELERATION = 750.0
STEPGEN_MAXACCEL = 937.5
SCALE = 40.0
FERROR = 1
MIN_FERROR = .25
HOME = 20.0
HOME_OFFSET = 0.0
HOME_SEARCH_VEL = -100.00
HOME_LATCH_VEL = 1.50000
HOME_FINAL_VEL = 25
HOME_IGNORE_LIMITS = YES
HOME_SEQUENCE = -2
VOLATILE_HOME = 1
USE_HOME_INDEX = NO

[JOINT_2]
TYPE = LINEAR
MIN_LIMIT = -0.001
MAX_LIMIT = 2740.0
MAX_VELOCITY = 100.0
MAX_ACCELERATION = 750.0
STEPGEN_MAXACCEL = 937.5
SCALE = 40.0
FERROR = 1
MIN_FERROR = .25
HOME = 20.0
HOME_OFFSET = 0.0
HOME_SEARCH_VEL = -100.00
HOME_LATCH_VEL = 1.50000
HOME_FINAL_VEL = 25
HOME_IGNORE_LIMITS = YES
HOME_SEQUENCE = -2
VOLATILE_HOME = 1
USE_HOME_INDEX = NO

[AXIS_Z]
MAX_VELOCITY = 25.0
MAX_ACCELERATION = 750.0
MIN_LIMIT = -250.0
MAX_LIMIT = 0.001

[JOINT_3]
TYPE = LINEAR
MIN_LIMIT = -250.0
MAX_LIMIT = 0.001
MAX_VELOCITY = 25.0
MAX_ACCELERATION = 750.0
STEPGEN_MAXACCEL = 937.5
SCALE = 200.0
FERROR = 1
MIN_FERROR = .25
HOME = -4.0
HOME_OFFSET = 0.000000
HOME_SEARCH_VEL = 20.00000
HOME_LATCH_VEL = -3.00000
HOME_IGNORE_LIMITS = YES
HOME_SEQUENCE = 0
VOLATILE_HOME = 1
USE_HOME_INDEX = NO

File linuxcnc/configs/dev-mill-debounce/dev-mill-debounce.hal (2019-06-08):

# Generated by stepconf 1.1 at Tue May 14 14:49:44 2019
# If you make changes to this file, they will be
# overwritten when you run stepconf again
loadrt [KINS]KINEMATICS
loadrt [EMCMOT]EMCMOT base_period_nsec=[EMCMOT]BASE_PERIOD servo_period_nsec=[EMCMOT]SERVO_PERIOD num_joints=[KINS]JOINTS
loadrt hal_parport cfg="1 out 2 out"
setp parport.0.reset-time 5000
loadrt stepgen step_type=0,0,0,0

addf parport.0.read base-thread
addf parport.1.read base-thread
addf stepgen.make-pulses base-thread
addf parport.0.write base-thread
addf parport.0.reset base-thread
addf parport.1.write base-thread

addf stepgen.capture-position servo-thread
addf motion-command-handler servo-thread
addf motion-controller servo-thread
addf stepgen.update-freq servo-thread
net spindle-cmd-rpm     <= spindle.0.speed-out
net spindle-cmd-rpm-abs <= spindle.0.speed-out-abs
net spindle-cmd-rps     <= spindle.0.speed-out-rps
net spindle-cmd-rps-abs <= spindle.0.speed-out-rps-abs
net spindle-at-speed    => spindle.0.at-speed

# pinout on DB25 for chinese controller (parport.0):
# http://www.savebase.com/infobase/downloads/breakout_board_stepper_driver/user_manual_5_axis_breakout_board.pdf
# PIN Function
# 1   X/Y/Z/A/B-Enabled (enable amplifier in stepconf)
# 2   X Step/pulse
# 3   Y-Direction
# 4   B Step/pulse
# 5   A-Direction
# 6   A-Step/pulse
# 7   z-Step/pulse
# 8   Z-Direction
# 9   Spindle motor
# 10  Input/X limit
# 11  Input/Y-limit
# 12  Input/Z-limit
# 13  Input/A-limit
# 14  X Direction
# 15  Input/E stop
# 16  y-Step/pulse
# 17  B-Direction
# 18-20 GND

#parport 2 (parport.1):
# 10 max-x
# 11 max-y1
# 12 min-z
# 13 max-y2
# 15 probe-in

net estop-ext       <= parport.0.pin-15-in

#setup debouncing for false triggers (8 limits/homes and one probe)
loadrt debounce cfg=9
setp debounce.0.delay 100 #this sets the delay 100 iterations of the base thread
addf debounce.0 base-thread

# debounce for touch off plate
net deb-probe-in debounce.0.0.in <= parport.1.pin-15-in-not
net probe-in debounce.0.0.out
net probe-in => motion.probe-input

#debounce for limit switches
net deb-min-home-x  debounce.0.1.in   <= parport.0.pin-10-in-not
net min-home-x      debounce.0.1.out
net deb-max-x       debounce.0.2.in   <= parport.1.pin-10-in
net max-x           debounce.0.2.out
net deb-min-home-y1 debounce.0.3.in   <= parport.0.pin-11-in-not
net min-home-y1     debounce.0.3.out
net deb-max-y1      debounce.0.4.in   <= parport.1.pin-11-in
net max-y1          debounce.0.4.out
net deb-min-home-y2 debounce.0.5.in   <= parport.0.pin-13-in-not
net min-home-y2     debounce.0.5.out
net deb-max-y2      debounce.0.6.in   <= parport.1.pin-13-in
net max-y2          debounce.0.6.out
net deb-max-home-z  debounce.0.7.in   <= parport.0.pin-12-in-not
net max-home-z      debounce.0.7.out
net deb-min-z       debounce.0.8.in   <= parport.1.pin-12-in
net min-z           debounce.0.8.out

# X axis
net xenable         => parport.0.pin-01-out
net xdir            => parport.0.pin-14-out
net xstep           => parport.0.pin-02-out
setp parport.0.pin-02-out-reset 1
setp parport.0.pin-02-out-invert 1

# Y axis
# joint 1
net y1dir            => parport.0.pin-03-out
net y1step           => parport.0.pin-16-out
setp parport.0.pin-16-out-reset 1

# joint 2 (using connector labelled a axis on board)
net y2dir            => parport.0.pin-05-out
setp parport.0.pin-05-out-invert 1
net y2step           => parport.0.pin-06-out
setp parport.0.pin-06-out-reset 1

# Z axis
net zdir            => parport.0.pin-08-out
net zstep           => parport.0.pin-07-out
setp parport.0.pin-07-out-reset 1

# joint_0 config (x axis)
setp stepgen.0.position-scale [JOINT_0]SCALE
setp stepgen.0.steplen 1
setp stepgen.0.stepspace 0
setp stepgen.0.dirhold 32000
setp stepgen.0.dirsetup 32000
setp stepgen.0.maxaccel [JOINT_0]STEPGEN_MAXACCEL
net xpos-cmd joint.0.motor-pos-cmd => stepgen.0.position-cmd
net xpos-fb stepgen.0.position-fb => joint.0.motor-pos-fb
net xstep <= stepgen.0.step
net xdir <= stepgen.0.dir
net xenable joint.0.amp-enable-out => stepgen.0.enable
net min-home-x => joint.0.home-sw-in
net min-home-x => joint.0.neg-lim-sw-in
net max-x => joint.0.pos-lim-sw-in

# joint_1 config (y1 axis)
setp stepgen.1.position-scale [JOINT_1]SCALE
setp stepgen.1.steplen 1
setp stepgen.1.stepspace 0
setp stepgen.1.dirhold 32000
setp stepgen.1.dirsetup 32000
setp stepgen.1.maxaccel [JOINT_1]STEPGEN_MAXACCEL
net y1pos-cmd joint.1.motor-pos-cmd => stepgen.1.position-cmd
net y1pos-fb stepgen.1.position-fb => joint.1.motor-pos-fb
net y1step <= stepgen.1.step
net y1dir <= stepgen.1.dir
net y1enable joint.1.amp-enable-out => stepgen.1.enable
net min-home-y1 => joint.1.home-sw-in
net min-home-y1 => joint.1.neg-lim-sw-in
net max-y1 => joint.1.pos-lim-sw-in

# joint_2 config (y2)
setp stepgen.2.position-scale [JOINT_2]SCALE
setp stepgen.2.steplen 1
setp stepgen.2.stepspace 0
setp stepgen.2.dirhold 32000
setp stepgen.2.dirsetup 32000
setp stepgen.2.maxaccel [JOINT_2]STEPGEN_MAXACCEL
net y2pos-cmd joint.2.motor-pos-cmd => stepgen.2.position-cmd
net y2pos-fb stepgen.2.position-fb => joint.2.motor-pos-fb
net y2step <= stepgen.2.step
net y2dir <= stepgen.2.dir
net y2enable joint.2.amp-enable-out => stepgen.2.enable
net min-home-y2 => joint.2.home-sw-in
net min-home-y2 => joint.2.neg-lim-sw-in
net max-y2 => joint.2.pos-lim-sw-in


# joint_3 (z axis)
setp stepgen.3.position-scale [JOINT_3]SCALE
setp stepgen.3.steplen 1
setp stepgen.3.stepspace 0
setp stepgen.3.dirhold 32000
setp stepgen.3.dirsetup 32000
setp stepgen.3.maxaccel [JOINT_3]STEPGEN_MAXACCEL
net zpos-cmd joint.3.motor-pos-cmd => stepgen.3.position-cmd
net zpos-fb stepgen.3.position-fb => joint.3.motor-pos-fb
net zstep <= stepgen.3.step
net zdir <= stepgen.3.dir
net zenable joint.3.amp-enable-out => stepgen.3.enable
net max-home-z => joint.3.home-sw-in
net max-home-z => joint.3.pos-lim-sw-in
net min-z => joint.3.neg-lim-sw-in

net estop-out <= iocontrol.0.user-enable-out
net estop-ext => iocontrol.0.emc-enable-in

loadusr -W hal_manualtoolchange
net tool-change iocontrol.0.tool-change => hal_manualtoolchange.change
net tool-changed iocontrol.0.tool-changed <= hal_manualtoolchange.changed
net tool-number iocontrol.0.tool-prep-number => hal_manualtoolchange.number
net tool-prepare-loopback iocontrol.0.tool-prepare => iocontrol.0.tool-prepared

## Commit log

2019-05-07 first commit of stepconf generated (working) config
    [custom.hal, custom_postgui.hal, postgui_backup.hal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]
2019-05-08 updated latency
    [test_mill.hal, test_mill.ini]
2019-05-08 added config for linuxcnc 2.8
    [custom.hal, custom_postgui.hal, postgui_backup.hal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]
2019-05-14 modifying stocl conf
    [custom.hal, custom_postgui.hal, dev-mill.hal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]
2019-05-14 new config
    [postgui_call_list.hal, pyvcp_options.hal, test-mill-2.8.hal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]
2019-05-14 working conf on big machine in test-mill
    [postgui_call_list.hal, pyvcp_options.hal, test-mill-2.8.hal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]
2019-05-14 started to change updated stepconf
    [dev-mill.ini]
2019-05-14 homing sorted for ini
    [dev-mill.ini]
2019-05-15 finsished configuring ini and hal file. now need to test
    [dev-mill.hal, dev-mill.ini]
2019-05-15 added homing comments
    [dev-mill.ini]
2019-05-19 directions modified
    [dev-mill.hal]
2019-05-19 plying wiht limits in real machine
    [dev-mill.hal, dev-mill.ini]
2019-05-20 hopefully homing is sorted
    [dev-mill.ini]
2019-05-20 my first gcode
    [cb.FCStd]
2019-05-20 homing machine works
    [dev-mill.hal, dev-mill.ini]
2019-05-20 new path that hopefully fits
    [cb.FCStd]
2019-05-22 updated test mill for home only
    [custom.hal, dev-mill.hal, postgui_call_list.hal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]
2019-05-22 no limit switches (think i flipped the bit accidentally in config file)
    [custom.hal, custom_postgui.hal, dev-mill-nolimit.hal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]
2019-05-22 working config, slow, 8 steps per pulse
    [dev-mill-nolimit.hal]
2019-05-23 looks like micorstepping makes no difference with speed
    [custom.hal, custom_postgui.hal, dev-mill-nolimit.hal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]
2019-05-24 working with permanent wiring
    [custom.hal, custom_postgui.hal, dev-mill-nolimit.hal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]
2019-05-24 added lasersnake
    [lasersnake.FCStd]
2019-05-25 sped things up a bit
    [dev-mill-nolimit.ini]
2019-05-25 cad filing
    [lasersnake.FCStd]
2019-05-25 updated lasersnake path
    [lasersnake.FCStd]
2019-05-27 bucket cut
    [suction bucket.FCStd]
2019-05-27 updated gcode for bucket
    [suction bucket.FCStd]
2019-05-27 started touch off plate stuff
    [custom.hal, custom_postgui.hal, dev-mill-touchoff.hal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]
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2019-05-28 saved changes to bucket
    [suction bucket.FCStd]
2019-05-28 changed test config for second port
    [postgui_call_list.hal, pyvcp_options.hal, test-mill-2.8.hal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]
2019-05-29 added path for bucket
    [bucket_newest.FCStd, cb.FCStd, suction bucket.FCStd]
2019-05-30 updated bucket plan
    [bucket_newest.FCStd]
2019-05-30 updated bucket path 9again)
    [bucket_newest.FCStd]
2019-05-30 updated drill job to work
    [bucket_newest.FCStd]
2019-06-02 working limits, estop and touch off plate (kind of)
    [dev-mill-nolimit.hal, dev-mill-touchoff.hal]
2019-06-02 touchoff started
    [custom_postgui.hal]
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2019-06-03 tidied up master branch
    [custom.hal, custom_postgui.hal, dev-mill-nolimit.hal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]
2019-06-03 ply cutting for vac extraction
    [ply_hole.FCStd]
2019-06-05 levels for retaining wall
    [oneinten.FCStd]
2019-06-06 making ply thing fancier
    [oneinten.FCStd]
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2019-06-08 added debouncing to hal file
    [custom.hal, custom_postgui.hal, dev-mill-debounce.hal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]
2019-06-08 attemping to sort out limit switch mapping
    [dev-mill-debounce.ini]
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2019-06-10 updated cad stuff for level
    [oneinten.FCStd]
2019-06-10 updated cad stuff for level and added tabs
    [oneinten.FCStd]
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2019-06-10 ready to cut ply
    [oneinten.FCStd]
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2019-06-11 made tags and speed bigger
    [oneinten_notag.FCStd]
2019-06-11 made tags reduced speed and plunge
    [oneinten_notag.FCStd]
2019-06-12 broke jobs up for levels
    [oneinten_notag.FCStd]
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2019-06-17 slots for pole jig
    [pole_jig.FCStd]
2019-06-17 created template for holding poles
    [pole_holder.FCStd]
2019-06-18 adding stuff for gig
    [pole_holder.FCStd, pole_holder.stp, pole_jig.FCStd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]
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2019-07-13 upgraded hardware to gt3 belt
    [custom.hal, custom_postgui.hal, dev-mill-gt3.hal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]
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2019-07-18 now have spindle control via linuxcnc
    [custom.hal, custom_postgui.hal, dev-mill-rs485.hal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]
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2019-08-07 trying with no micorsteps
    [custom.hal, custom_postgui.hal, dev-mill-gt3.hal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]
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2019-08-10 Revert "Merge branch 'dev-2.8' of https://github.com/marcass/cnc_machine into dev-2.8"
    This reverts commit cbc0bb648ad95ba072a52db232ff597c5fcce2d7, reversing
    changes made to c41557fa88b35bf5faaf7bafbfd4afa388d5a8ae.
    [custom.hal, custom_postgui.hal, dev-mill-debounce.hal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]
2019-08-10 Revert "Revert "Merge branch 'dev-2.8' of https://github.com/marcass/cnc_machine into dev-2.8""
    This reverts commit 3e97d5206c50760037087d3354840e0cb9592390.
    [custom.hal, custom_postgui.hal, dev-mill-gt3.hal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]
2019-08-10 added config for 4mocirsteps
    [custom.hal, custom_postgui.hal, dev-mill-4microsteps.hal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]
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2019-11-09 fixed rapid to hme button
    [custom_postgui.hal, dev-mill-4microsteps.ini]
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2019-12-16 removed redundtant machines and ujpdated tool table
    [custom.hal, custom_postgui.hal, dev-mill-nomicrosteps.hal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]
2020-05-04 Added dxf's for laser cutting. Need to round corners on hats
    [hat_1279.dxf, hat_2390.dxf, hat_2490.dxf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]
2020-05-05 rounded corners, halved long hat
    [Verandah_plates.dxf, hat_1279.dxf, hat_2390.dxf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]
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2020-05-06 removed 20mm form botton
    [Verandah_front.dxf, Verandah_outside.dxf, verandah_inside.dxf]
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2020-06-02 altered fixing points
    [side_1530.dxf, side_1730.dxf, side_2110.dxf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]
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2021-06-20 updated stuff for spindle debugging
    [custom.hal, custom_postgui.hal]
2021-06-20 increased cycle time and started a default machine for sale
    [custom.hal, custom_postgui.hal, default_machine.hal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]
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2021-07-23 added nc files for knife block cut
    [knife_block.FCStd]
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2021-07-24 added feed and speed for milling
    [knife_block.FCStd]
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2022-08-20 Changed file structure for new setup
    [Verandah_front.dxf, Verandah_outside.dxf, bars.FCStd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]
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
